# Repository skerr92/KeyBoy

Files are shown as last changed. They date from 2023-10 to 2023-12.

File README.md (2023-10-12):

# KeyBoy
Home of all things KeyBoy - Games, board files, parts lists, and more!

### NOTICE ###
Licensed under MIT License, see LICENSE for details

### About ###
This repository holds all things for the KeyBoy. 

Currently we just have the EAGLE schematic and board files available, thoguh KiCAD files will be coming soon.

Additionally, the BOM and manufacturing files will be coming once with final design is validated.

Once you have hardware in hand, you will need to put the CircuitPython ESP32-S3 Mini Dev Kit image onto the ESP32-S3 onboard.

From there, copy over the required libraries listed in the code.py under the Firmware directory.

Copy the code.py file to your CIRCUITPY drive and it should work.

The game in the code.py is a time dot chase game.

This uses a 1.3" ST7789 display which can be purchased from Adafruit.

### 3D Printed Case ###
Once I receive the next iteration of the board, I will be uploading a usable case here that can be printed on either resin or FDM 3D printers.
A CircuitPython board definition will be coming soon.

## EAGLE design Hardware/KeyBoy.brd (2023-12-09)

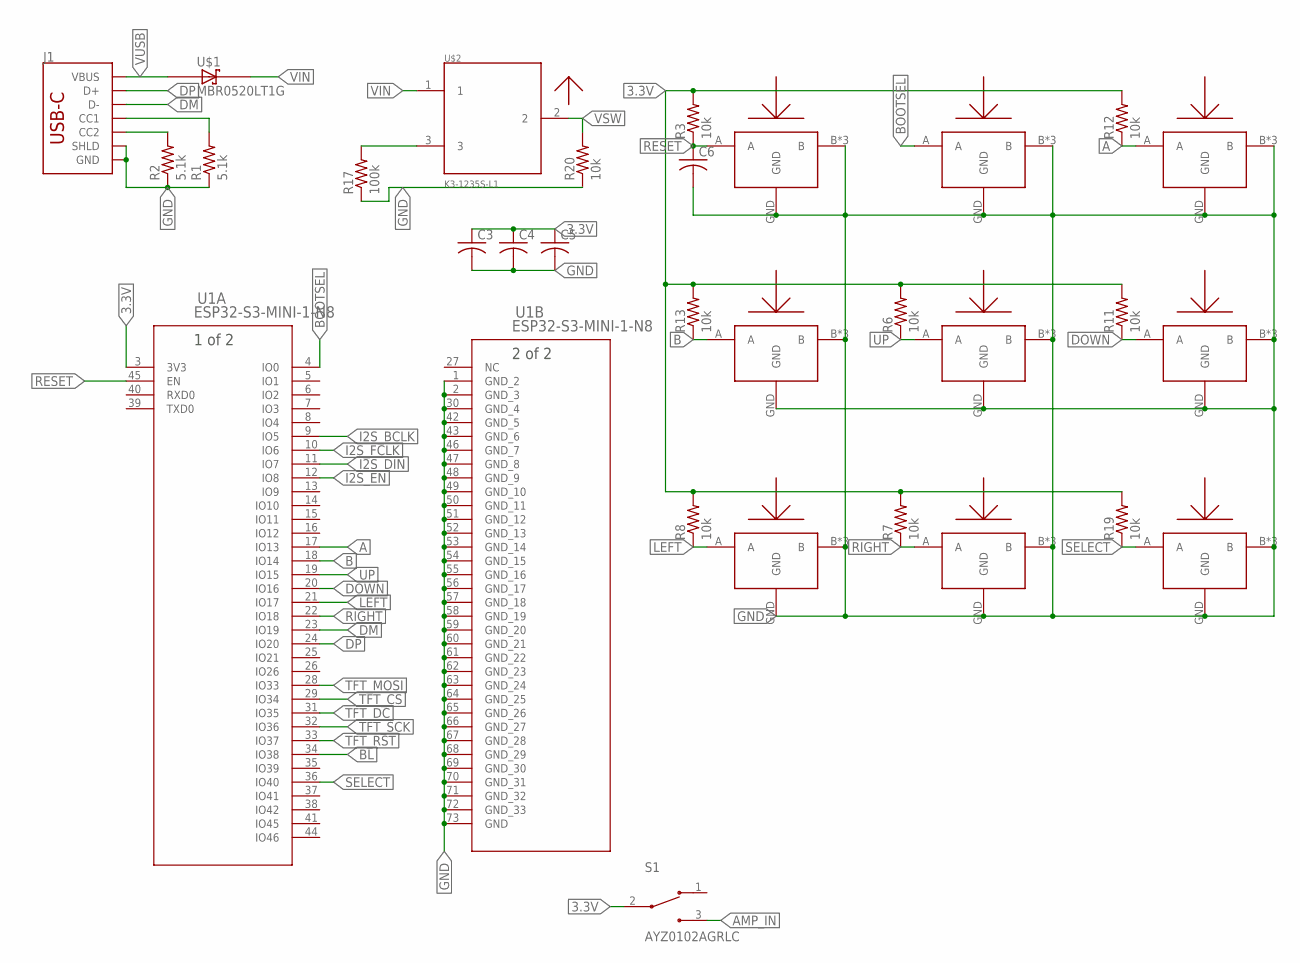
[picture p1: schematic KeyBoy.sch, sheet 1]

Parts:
A: SOF-232HST; 3.3X2.9
B: SOF-232HST; 3.3X2.9
BOOTSEL: SOF-232HST; 3.3X2.9
C3, C4, C5, C6: C-USC0402; C0402
DOWN: SOF-232HST; 3.3X2.9
J1: USB_C_2-LAYER_PADS; USB-C-16P-2LAYER-PADS
LEFT: SOF-232HST; 3.3X2.9
R1, R2: 5.1k; R0402
R3, R6, R7, R8, R11, R12, R13, R19, R20: 10k; R0402
R17: 100k; R0402
RESET: SOF-232HST; 3.3X2.9
RIGHT: SOF-232HST; 3.3X2.9
S1: AYZ0102AGRLC; SW_AYZ0102AGRLC
SELECT: SOF-232HST; 3.3X2.9
U1: ESP32-S3-MINI-1-N8; ESP32-S2-MINI-1-N4_EXP
U$1: MBR0520LT1G; SOD3716X117(SOD-123)
U$2: K3-1235S-L1
UP: SOF-232HST; 3.3X2.9

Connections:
3.3V: C3.1, C4.1, C5.1, R3.2, R6.2, R7.2, R8.2, R11.2, R12.2, R13.2, R19.2, S1.2, U1.3 (3V3); also elsewhere on the board
A: A.A, R12.1, U1.17 (IO13)
AMP_IN: S1.3; also elsewhere on the board
B: B.A, R13.1, U1.18 (IO14)
BL: U1.34 (IO38); also elsewhere on the board
BOOTSEL: BOOTSEL.A, U1.4 (IO0)
DM: J1.A7 (D-), J1.B7 (D-), U1.23 (IO19)
DOWN: DOWN.A, R11.1, U1.20 (IO16)
DP: J1.A6 (D+), J1.B6 (D+), U1.24 (IO20)
GND: A.B, A.B2 (B), A.B3 (B), A.GND, B.B, B.B2 (B), B.B3 (B), B.GND, BOOTSEL.B, BOOTSEL.B2 (B), BOOTSEL.B3 (B), BOOTSEL.GND, C3.2, C4.2, C5.2, C6.2, DOWN.B, DOWN.B2 (B), DOWN.B3 (B), DOWN.GND, J1.GND, J1.GND2 (GND), J1.P$1 (SHLD), J1.P$2 (SHLD), J1.P$3 (SHLD), J1.P$4 (SHLD), J1.SHLD1 (SHLD), J1.SHLD2 (SHLD), J1.SHLD3 (SHLD), J1.SHLD4 (SHLD), LEFT.B, LEFT.B2 (B), LEFT.B3 (B), LEFT.GND, R1.1, R2.1, R17.1, R20.1, RESET.B, RESET.B2 (B), RESET.B3 (B), RESET.GND, RIGHT.B, RIGHT.B2 (B), RIGHT.B3 (B), RIGHT.GND, SELECT.B, SELECT.B2 (B), SELECT.B3 (B), SELECT.GND, U1.1 (GND_2), U1.2 (GND_3), U1.30 (GND_4), U1.42 (GND_5), U1.43 (GND_6), U1.46 (GND_7), U1.47 (GND_8), U1.48 (GND_9), U1.49 (GND_10), U1.50 (GND_11), U1.51 (GND_12), U1.52 (GND_13), U1.53 (GND_14), U1.54 (GND_15), U1.55 (GND_16), U1.56 (GND_17), U1.57 (GND_18), U1.58 (GND_19), U1.59 (GND_20), U1.60 (GND_21), U1.61 (GND_22), U1.62 (GND_23), U1.63 (GND_24), U1.64 (GND_25), U1.65 (GND_26), U1.66 (GND_27), U1.67 (GND_28), U1.68 (GND_29), U1.69 (GND_30), U1.70 (GND_31), U1.71 (GND_32), U1.72 (GND_33), U1.73 (GND), UP.B, UP.B2 (B), UP.B3 (B), UP.GND; also elsewhere on the board
I2S_BCLK: U1.9 (IO5); also elsewhere on the board
I2S_DIN: U1.11 (IO7); also elsewhere on the board
I2S_EN: U1.12 (IO8); also elsewhere on the board
I2S_FCLK: U1.10 (IO6); also elsewhere on the board
LEFT: LEFT.A, R8.1, U1.21 (IO17)
unnamed: J1.A5 (CC1), R1.2
unnamed: J1.B5 (CC2), R2.2
unnamed: R17.2, U$2.3
RESET: C6.1, R3.1, RESET.A, U1.45 (EN)
RIGHT: R7.1, RIGHT.A, U1.22 (IO18)
SELECT: R19.1, SELECT.A, U1.36 (IO40)
TFT_CS: U1.29 (IO34); also elsewhere on the board
TFT_DC: U1.31 (IO35); also elsewhere on the board
TFT_MOSI: U1.28 (IO33); also elsewhere on the board
TFT_RST: U1.33 (IO37); also elsewhere on the board
TFT_SCK: U1.32 (IO36); also elsewhere on the board
UP: R6.1, U1.19 (IO15), UP.A
VIN: U$1.1 (C), U$2.1; also elsewhere on the board
VSW: R20.2, U$2.2; also elsewhere on the board
VUSB: J1.VBUS1 (VBUS), J1.VBUS2 (VBUS), U$1.2 (A); also elsewhere on the board

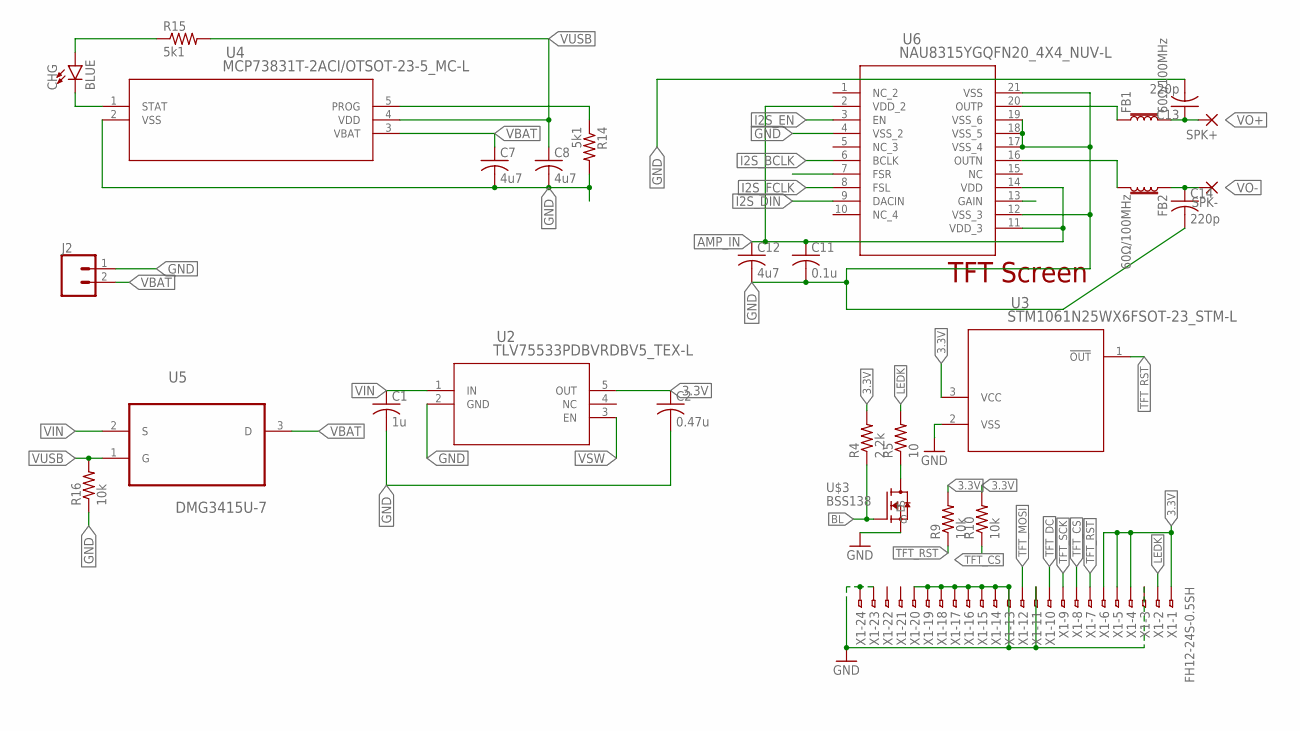
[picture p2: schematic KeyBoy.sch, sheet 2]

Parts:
C1: 1u; C0402
C2: 0.47u; C0402
C7, C8, C12: 4u7; C0603
C11: 0.1u; C0603
C13, C14: 220p; C0603
CHG: BLUE; LED-0603
FB1, FB2: 60Ω/100MHz; 0603
J2: CONN_02-JST-2MM-SMT; JST-2-SMD
R4: 2.2k; R0603
R5: 10; R0402
R9, R10, R16: 10k; R0402
R14, R15: 5k1; R0603
SPK+: SMD5; SMD2,54-5,08
SPK-: SMD5; SMD2,54-5,08
U2: TLV75533PDBVRDBV5_TEX-L; DBV5_TEX-L
U3: STM1061N25WX6FSOT-23_STM-L; SOT-23_STM-L
U4: MCP73831T-2ACI/OTSOT-23-5_MC-L; SOT-23-5_MC-L
U5: DMG3415U-7; SOT95P240X105-3N
U6: NAU8315YGQFN20_4X4_NUV-L; QFN20_4X4_NUV-L
U$3: BSS138
X1: FH12-24S-0.5SH

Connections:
3.3V: C2.1, R4.2, R9.2, R10.2, U2.5 (OUT), U3.3 (VCC), X1.1, X1.4, X1.5, X1.6; also elsewhere on the board
AMP_IN: C11.1, C12.1, U6.2 (VDD_2), U6.11 (VDD_3), U6.14 (VDD); also elsewhere on the board
BL: R4.1, U$3.G; also elsewhere on the board
GND: C1.2, C2.2, C7.2, C8.2, C11.2, C12.2, C13.2, C14.2, J2.1 (2), R14.2, R16.1, U2.2 (GND), U3.2 (VSS), U4.2 (VSS), U6.4 (VSS_2), U6.12 (VSS_3), U6.17 (VSS_4), U6.18 (VSS_5), U6.19 (VSS_6), U6.21 (VSS), U$3.S, X1.3, X1.11, X1.13, X1.14, X1.15, X1.16, X1.17, X1.18, X1.19, X1.20, X1.23, X1.24; also elsewhere on the board
I2S_BCLK: U6.6 (BCLK); also elsewhere on the board
I2S_DIN: U6.9 (DACIN); also elsewhere on the board
I2S_EN: U6.3 (EN); also elsewhere on the board
I2S_FCLK: U6.8 (FSL); also elsewhere on the board
LEDK: R5.2, X1.2
unnamed: R14.1, U4.5 (PROG)
unnamed: FB1.1, U6.20 (OUTP)
unnamed: R5.1, U$3.D
unnamed: FB2.2, U6.16 (OUTN)
unnamed: CHG.C, U4.1 (STAT)
unnamed: CHG.A, R15.1
TFT_CS: R10.1, X1.8; also elsewhere on the board
TFT_DC: X1.10; also elsewhere on the board
TFT_MOSI: X1.12; also elsewhere on the board
TFT_RST: R9.1, U3.1 (!OUT), X1.7; also elsewhere on the board
TFT_SCK: X1.9; also elsewhere on the board
VBAT: C7.1, J2.2 (1), U4.3 (VBAT), U5.3 (D)
VIN: C1.1, U2.1 (IN), U5.2 (S); also elsewhere on the board
VO+: C13.1, FB1.2, SPK+.1
VO-: C14.1, FB2.1, SPK-.1
VSW: U2.3 (EN); also elsewhere on the board
VUSB: C8.1, R15.2, R16.2, U4.4 (VDD), U5.1 (G); also elsewhere on the board

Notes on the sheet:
TFT Screen

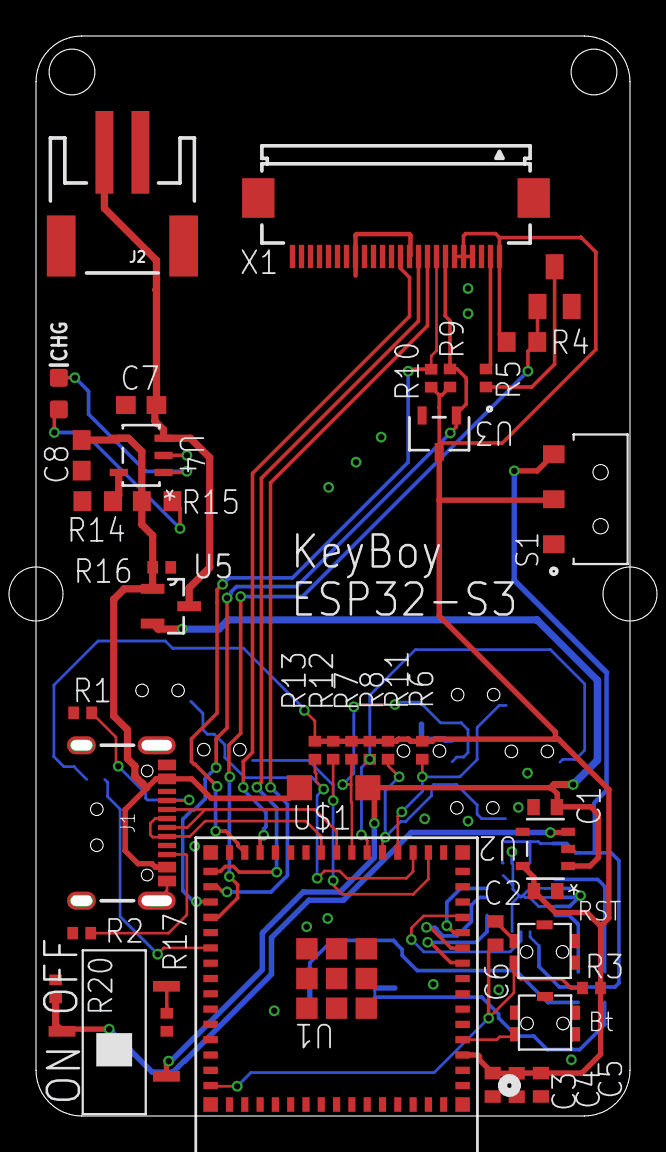
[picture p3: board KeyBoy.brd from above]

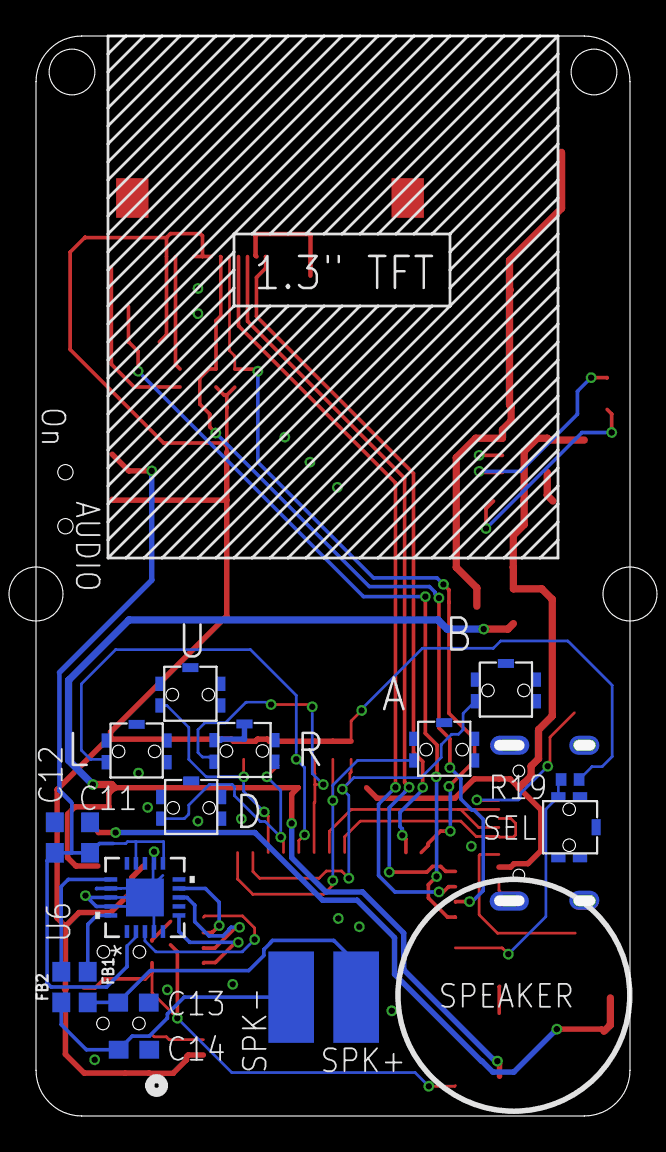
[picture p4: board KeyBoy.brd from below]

Board: 2 copper layers, 33.0 x 60.0 mm, 58 parts (17 on the bottom side), 40 nets.

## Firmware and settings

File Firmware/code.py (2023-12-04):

import board, displayio, time
from adafruit_st7789 import ST7789
import busio, microcontroller, pwmio
from digitalio import DigitalInOut, Direction
from Loose_Cows import Loose_Cows
from adafruit_display_text import label
import terminalio, adafruit_imageload, io, storage

displayio.release_displays()
brightness = 5
bl = pwmio.PWMOut(board.IO38, frequency=100, duty_cycle=int(brightness * 2 * 65535 / 100))
spi = busio.SPI(clock=microcontroller.pin.GPIO36, MOSI=microcontroller.pin.GPIO33)
LooseCowsScore = 0
try:
    game1_score = io.open('/cows.txt','rt')
    temp = game1_score.readline()
    game1_score.close()
    if (int(temp) > 0):
        LooseCowsScore = int(temp)
        print("Loose Cows High Score: ", LooseCowsScore)
except OSError:
    print("no score file")


tft_dc = board.IO35
tft_cs = microcontroller.pin.GPIO34

# setup user buttons
R = DigitalInOut(board.IO18)
R.direction = Direction.INPUT

L = DigitalInOut(board.IO17)
L.direction = Direction.INPUT

U = DigitalInOut(board.IO15)
U.direction = Direction.INPUT

D = DigitalInOut(board.IO16)
D.direction = Direction.INPUT

A = DigitalInOut(board.IO13)
A.direction = Direction.INPUT

B = DigitalInOut(board.IO14)
B.direction = Direction.INPUT

display_bus = displayio.FourWire(
    spi, command=tft_dc, chip_select=tft_cs, reset=board.IO37
)

display = ST7789(display_bus, width=240, height=240, rowstart=80, rotation=0)

splash = displayio.Group()
display.show(splash)
game = Loose_Cows.LooseCows(splash, A, B, U, D, L, R, LooseCowsScore)
game_selected = 1;

menu_bitmap = displayio.Bitmap(240,240,1)
menu_palette = displayio.Palette(1)
menu_palette[0] = 0xFFFFFF
menu_group = displayio.Group()
menu = displayio.TileGrid(menu_bitmap, pixel_shader=menu_palette, x=0, y=0)
menu_group.append(menu)
game1_group = displayio.Group(scale=2, x=80,y=100)
game1_text = "Loose Cows"
game1_txt_area = label.Label(terminalio.FONT, text=game1_text, color=0x000000)
game1_group.append(game1_txt_area)
menu_group.append(game1_group)
game_selector = displayio.Bitmap(15,15,1)
game_selector_p = displayio.Palette(1)
game_selector_p[0] = 0xFF0000
selector_sprite = displayio.TileGrid(game_selector, pixel_shader=game_selector_p, x=50, y=95)
menu_group.append(selector_sprite)
nogame = True
menu_up = False
while True:
    if game_selected == 0:
        splash.remove(menu_group)
        menu_up = False
        [nogame, LooseCowsScore] = game.Game()
        try:
            game1_score = io.open("/cows.txt", mode='wt')
            game1_score.write(str(LooseCowsScore))
            game1_score.close()
        except OSError:
            print("Can't save in programming mode")
        time.sleep(1)
    if nogame:
        game_selected = 1
        if menu_up == False:
            splash.append(menu_group)
            menu_up = True
    if game_selected == 1:
        if A.value == 0:
            game_selected = 0
            nogame = False
    time.sleep(0.5)

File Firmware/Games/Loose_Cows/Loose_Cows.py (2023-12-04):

# SPDX-FileCopyrightText: Copyright (c) 2023 Seth Kerr
#
# SPDX-License-Identifier: MIT

import time, displayio
from digitalio import DigitalInOut, Direction
from adafruit_display_text import label
import terminalio, adafruit_imageload, random

__version__ = "0.0.0+auto.0"
__repo__ = ""

class LooseCows:

    def __init__(self, splash, A_btn, B_btn, Up_btn, Dwn_btn, L_btn, R_btn, HighScore):
        self._splash = splash
        self._A = A_btn
        self._B = B_btn
        self._U = Up_btn
        self._D = Dwn_btn
        self._L = L_btn
        self._R = R_btn
        self._HighScore = HighScore
        self._exit = False
        self._pause = False
        self._menu_bitmap = displayio.Bitmap(120,120,1)
        self._color_palette = displayio.Palette(1)
        self._color_palette[0] = 0xFFFFFF #white
        self.menu_group = displayio.Group()
        self._menu = displayio.TileGrid(self._menu_bitmap, pixel_shader=self._color_palette,
                                        x=60, y=60)
        self._continue_group = displayio.Group(scale=2, x=80, y=70)
        self._continue_text = "Continue"
        self._cont_txt_area = label.Label(terminalio.FONT, text=self._continue_text, color=0x000000)
        self._continue_group.append(self._cont_txt_area)
        self._exit_group = displayio.Group(scale=2, x=80, y=90)
        self._exit_text = "Exit"
        self._exit_txt_area = label.Label(terminalio.FONT, text=self._exit_text, color=0xFF0000)
        self._exit_group.append(self._exit_txt_area)
        self.menu_group.append(self._menu)
        self.menu_group.append(self._continue_group)
        self.menu_group.append(self._exit_group)
        self._select = displayio.Bitmap(10,10,1)
        self._select_palette = displayio.Palette(1)
        self._select_palette[0] = 0x000000
        self._select_sprite = displayio.TileGrid(self._select, pixel_shader=self._select_palette,
                                                 x=65, y=70)
        self._select_pos = 0
        self.menu_group.append(self._select_sprite)
        self.farmer, self.palette = adafruit_imageload.load("/lib/Loose_Cows/farmer sprites_16b2.gif",
                                                    bitmap=displayio.Bitmap,
                                                    palette=displayio.Palette)

        self.field, self.fpalette = adafruit_imageload.load("/lib/Loose_Cows/background_sheet.gif",
                                                    bitmap=displayio.Bitmap,
                                                    palette = displayio.Palette)

    def TearDownGame(self):
        while len(self._splash) > 0:
            print("tearing down game")
            self._splash.pop()

    def ToggleMenu(self):
        if self._pause == True:
            self._splash.append(self.menu_group)
        if self._pause == False:
            self._splash.remove(self.menu_group)

    def Game(self):
        self._exit = False
        background = displayio.TileGrid(self.field, pixel_shader=self.fpalette,
                                        width = 15,
                                        height = 15,
                                        tile_width = 16,
                                        tile_height = 16)

        self._splash.append(background)

        background[0,0] = 0
        background[14,0] = 2
        background[0,14] = 6
        background[14,14] = 8

        for x in range(1,14):
            background[x,0] = 1
            background[x,14] = 7

        for y in range(1,14):
            background[0,y] = 3
            background[14,y] = 5

        for x in range(1,14):
            for y in range(1,14):
                background[x,y] = 4

        sprite = displayio.TileGrid(self.farmer, pixel_shader=self.palette,
                                    width = 1,
                                    height = 1,
                                    tile_width = 16,
                                    tile_height = 16,
                                    x=110, y=110)
        self._splash.append(sprite)

        x_rand = random.randint(20,220)
        y_rand = random.randint(20,220)

        cow_sprite = displayio.TileGrid(self.farmer, pixel_shader=self.palette,
                                    width = 1,
                                    height = 1,
                                    tile_width = 16,
                                    tile_height = 16,
                                    x=x_rand, y=y_rand)
        cow_sprite[0] = 3
        self._splash.append(cow_sprite)

        points = 0
        timeleft = 10
        # Draw a label
        text_group = displayio.Group(scale=2, x=140, y=30)
        text = "COWS: "
        tg2 = displayio.Group(scale=2, x=200, y=30)
        t2 = str(points)
        tg3 = displayio.Group(scale=2, x=20, y=30)
        t3 = str(timeleft)
        tg4 = displayio.Group(scale=2, x=50, y=30)
        hs = "HS: " + str(self._HighScore)
        text_area = label.Label(terminalio.FONT, text=text, color=0x000000)
        t2_area = label.Label(terminalio.FONT, text=t2, color=0x000000)
        t3_area = label.Label(terminalio.FONT, text=t3, color=0x000000)
        t4_area = label.Label(terminalio.FONT, text=hs, color=0x000000)
        text_group.append(text_area)  # Subgroup for text scaling
        tg2.append(t2_area)
        tg3.append(t3_area)
        tg4.append(t4_area)
        self._splash.append(text_group)
        self._splash.append(tg2)
        self._splash.append(tg3)
        self._splash.append(tg4)

        previous_monotonic = time.monotonic()
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

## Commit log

2023-10-15 Add schematics and brd files
    [KeyBoy.brd, KeyBoy.sch]
2023-12-04 fixing bugs
    1. fix bug with timer running out after 50 cows caught
    2. fixing main code.py
    3. added the start of two additional games
    [AerialDogFight.py, Dungeons_CYL.py, Loose_Cows.py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]
2023-12-09 updating hardware files
    [KeyBoy.brd, KeyBoy.sch]

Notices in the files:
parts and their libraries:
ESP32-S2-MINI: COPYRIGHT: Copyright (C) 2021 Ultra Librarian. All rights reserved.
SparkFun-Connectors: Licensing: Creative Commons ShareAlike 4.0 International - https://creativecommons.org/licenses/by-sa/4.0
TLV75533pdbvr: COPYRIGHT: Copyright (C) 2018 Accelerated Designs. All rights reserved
